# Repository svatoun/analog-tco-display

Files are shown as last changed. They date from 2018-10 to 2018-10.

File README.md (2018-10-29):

# analog-tco-display

Projekt se skládá z 2 částí: Analogové TCO a Zobrazovač obsazení

## Analogové TCO
**TCO je ovladač ANALOGOVÉHO kolejiště do ovládacího pultu**, pracuje s tlačítky (spínači) nebo přepínači. Čte stav tlačítek, sleduje změny a pomocí sběrnice RS485 odesílá jednotlivým výkonným zařízením pod kolejištěm. Sběrnice nahrazuje samostatné spínací / povelové vodiče vedoucí z pultu k jednotlivým servům, přestavníkům apod. TCO si vystačí se 3 vodiči (U+, U- a GND) a dokáže po nich přenést velké libovolné množství povelů.

Bežné "analogově řízené" kolejiště využívá jednoduchého spínání, tedy na každé zařízení (přestavník, lampa, světlo návěstidla atd) padne jeden vodič. Jejich množství může lehce vyčerpat vodiče v kabelu propojující ovládací panel s kolejištěm.

**POZOR** jedná se o ovládání ANALOGOVÉHO kolejiště, u digitálního kolejiště pomocí _XPressNet_ je pro komunikaci s centrálou použitá sicestejná kabeláž ale **jiný, standardizovaný, protokol** ! Komunikace a možnosti tohoto "analogového TCO" v žádném případě nedosahuje robustnosti a šíře protokolu XpressNet nebo LocoNet.

TCO se **konfiguruje** pomocí integrovaného USB portu v Arduinu, zapojeného do PC. 

Více viz [Analogové TCO](http://cs.ttodbocna.wikia.com/wiki/Analog_TCO)

## Zobrazení obsazení
Skládá se z několika částí:
- Proudové detektory obsazení uzpůsobené pro analogový provoz
- Enkodér detektorů pro sběrnici S88 (stejná jako se používá u digitalních kolejišť)
- Zobrazovací jednotka v ovládacím pultu
Umožňuje přenášet až 128 detekovaných úseků a zobrazovat jejich stav na ovládacím pultu. Umožňuje také do přenášených dat zapojit jiný tzp detektorů, 
např. jazýčková relé, optické senzory atd. 

Podrobnější popis bude doplněn.

## Celková "architektura"
Jak spolu spolupracují TCO, Display, proudove detektory atd atd je [vysvětleno ve Wiki](http://cs.ttodbocna.wikia.com/wiki/Architektura_Analog)

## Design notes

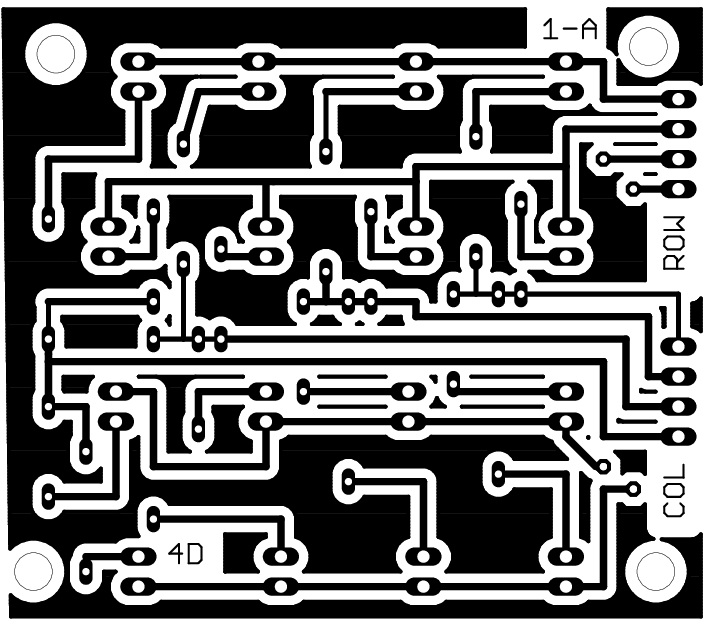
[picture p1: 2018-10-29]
eagle/tco/matrix4x4-b.png

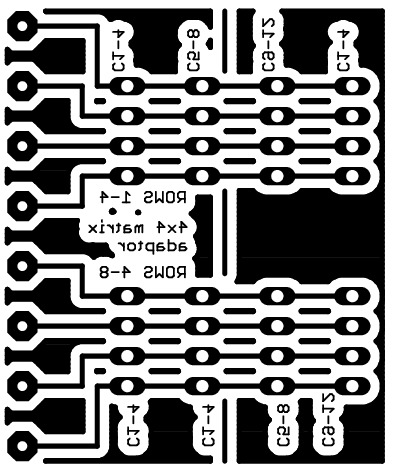
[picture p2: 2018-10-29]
eagle/tco/matrixkey-adapter.png

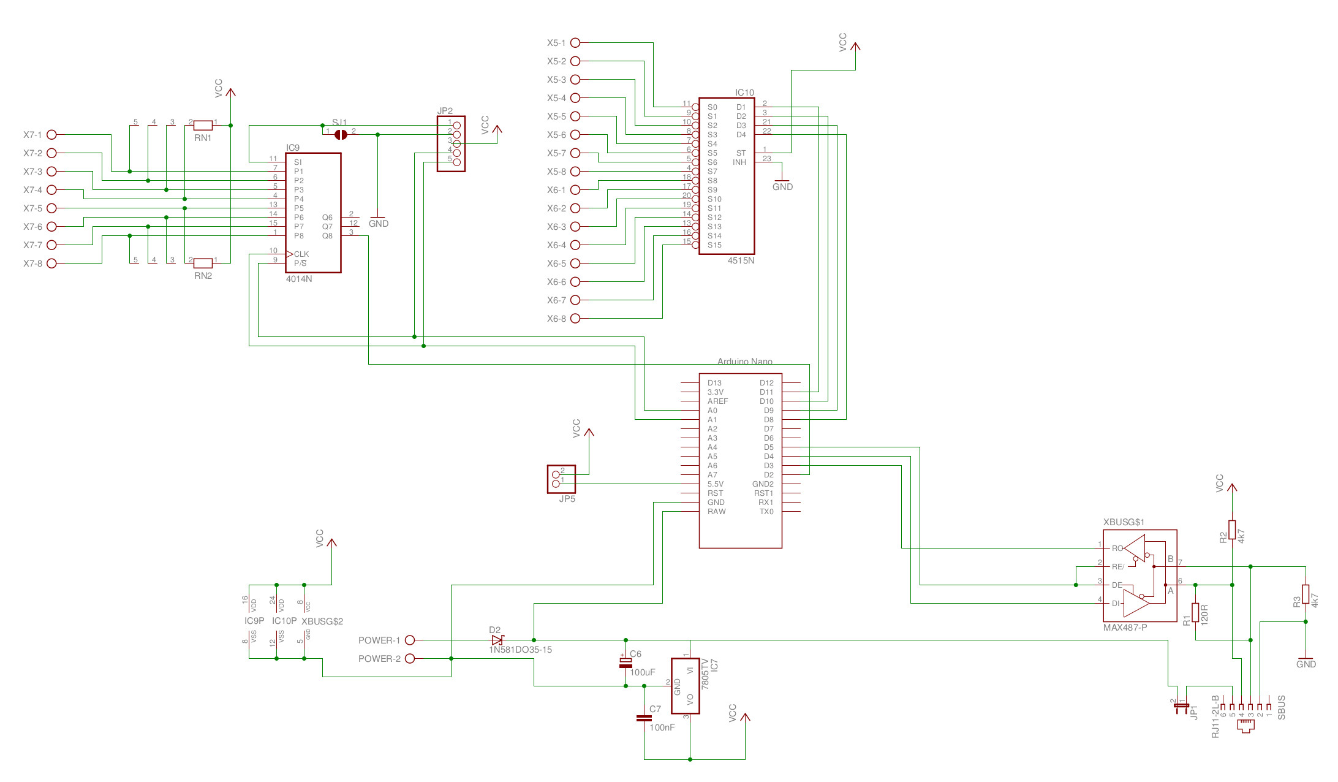
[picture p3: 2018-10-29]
eagle/tco/analogTCO-RJ-alone-ext-schema.jpg

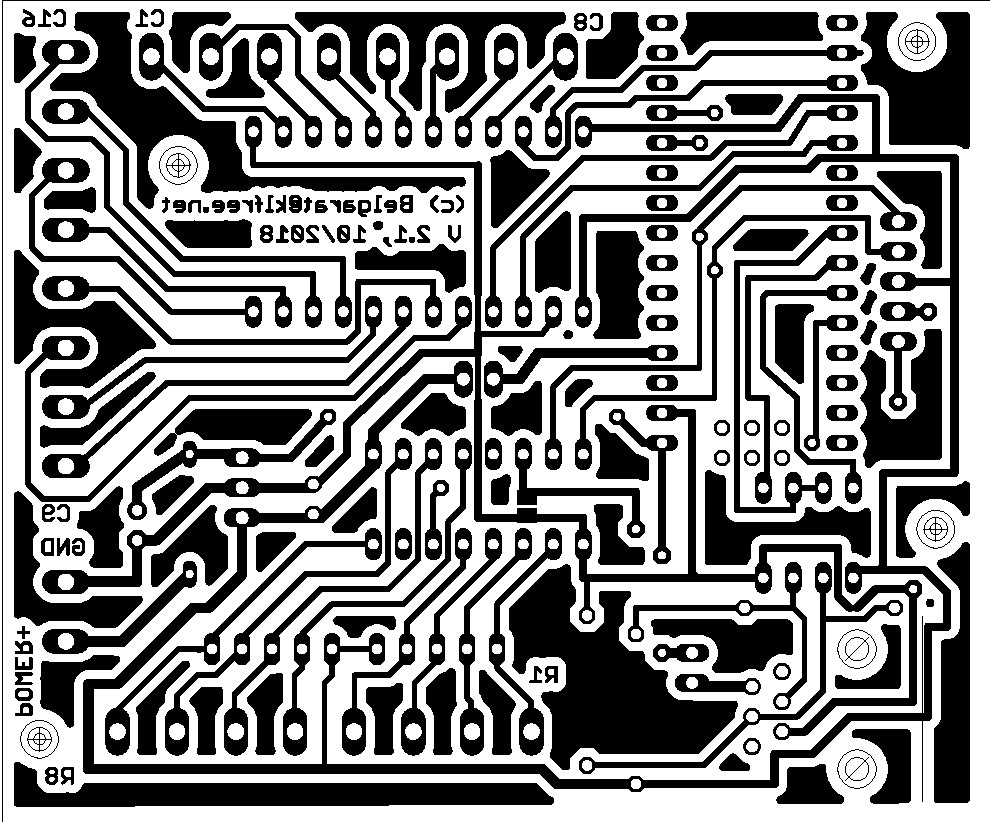
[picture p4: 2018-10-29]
eagle/tco/analogTCO-RJ-alone-ext.jpg

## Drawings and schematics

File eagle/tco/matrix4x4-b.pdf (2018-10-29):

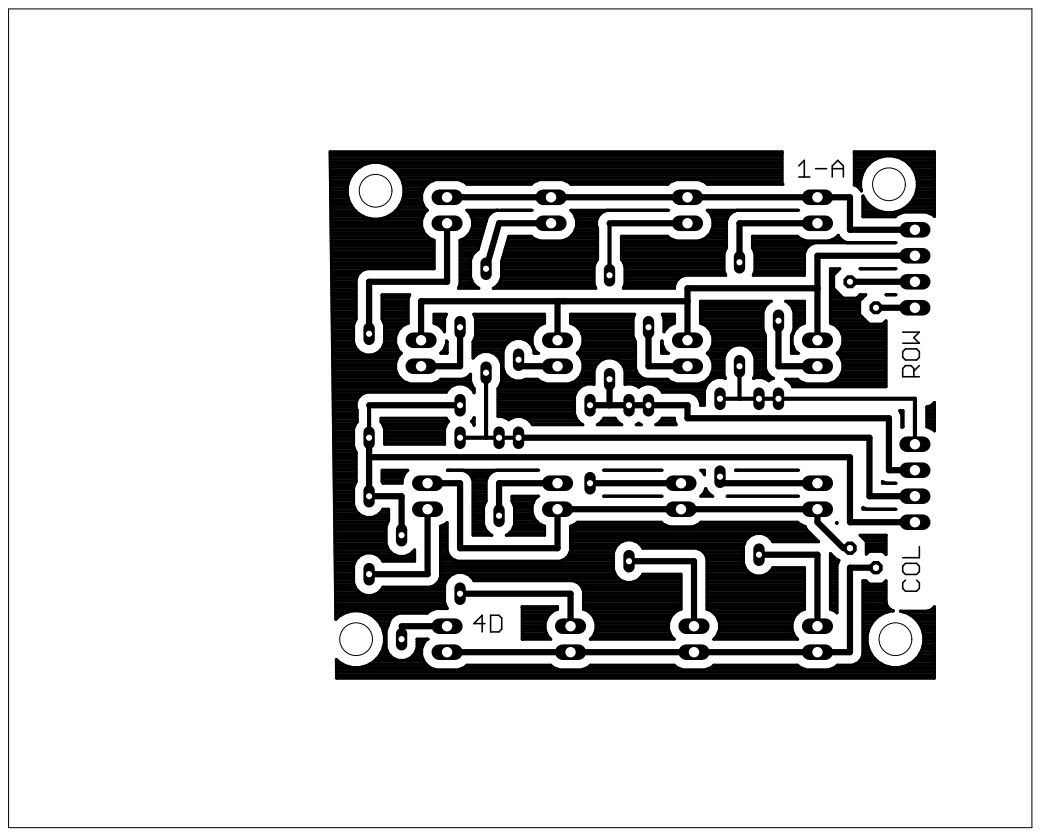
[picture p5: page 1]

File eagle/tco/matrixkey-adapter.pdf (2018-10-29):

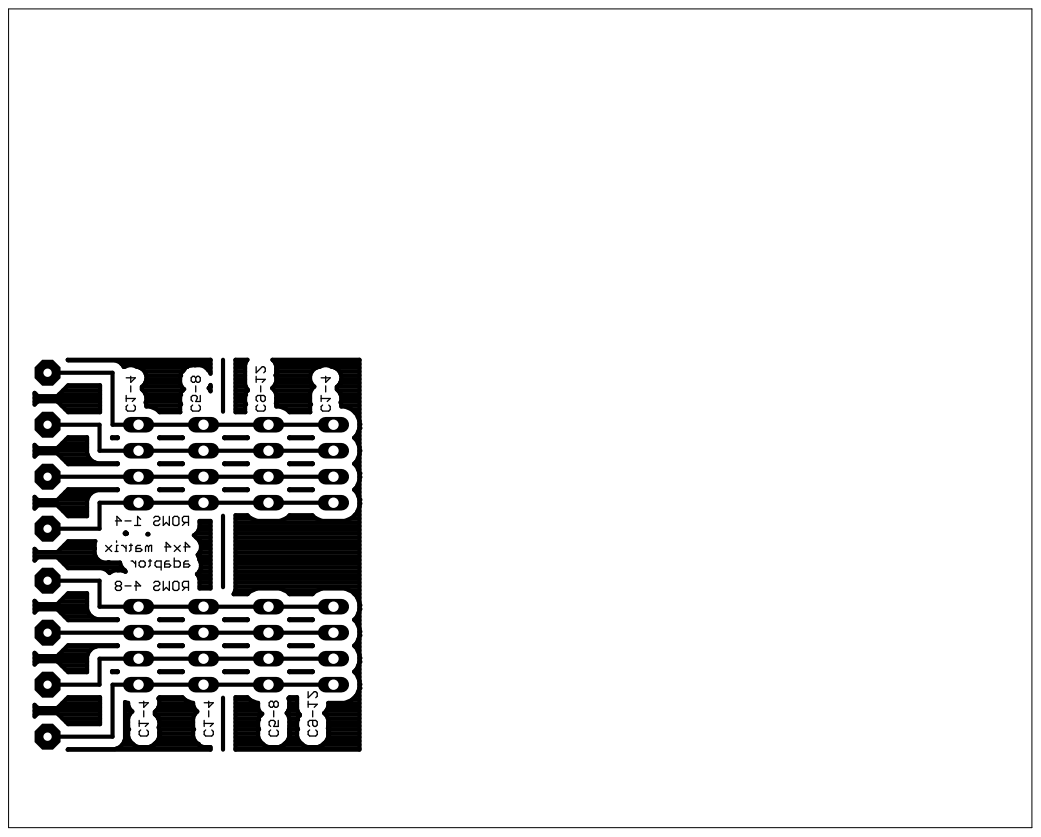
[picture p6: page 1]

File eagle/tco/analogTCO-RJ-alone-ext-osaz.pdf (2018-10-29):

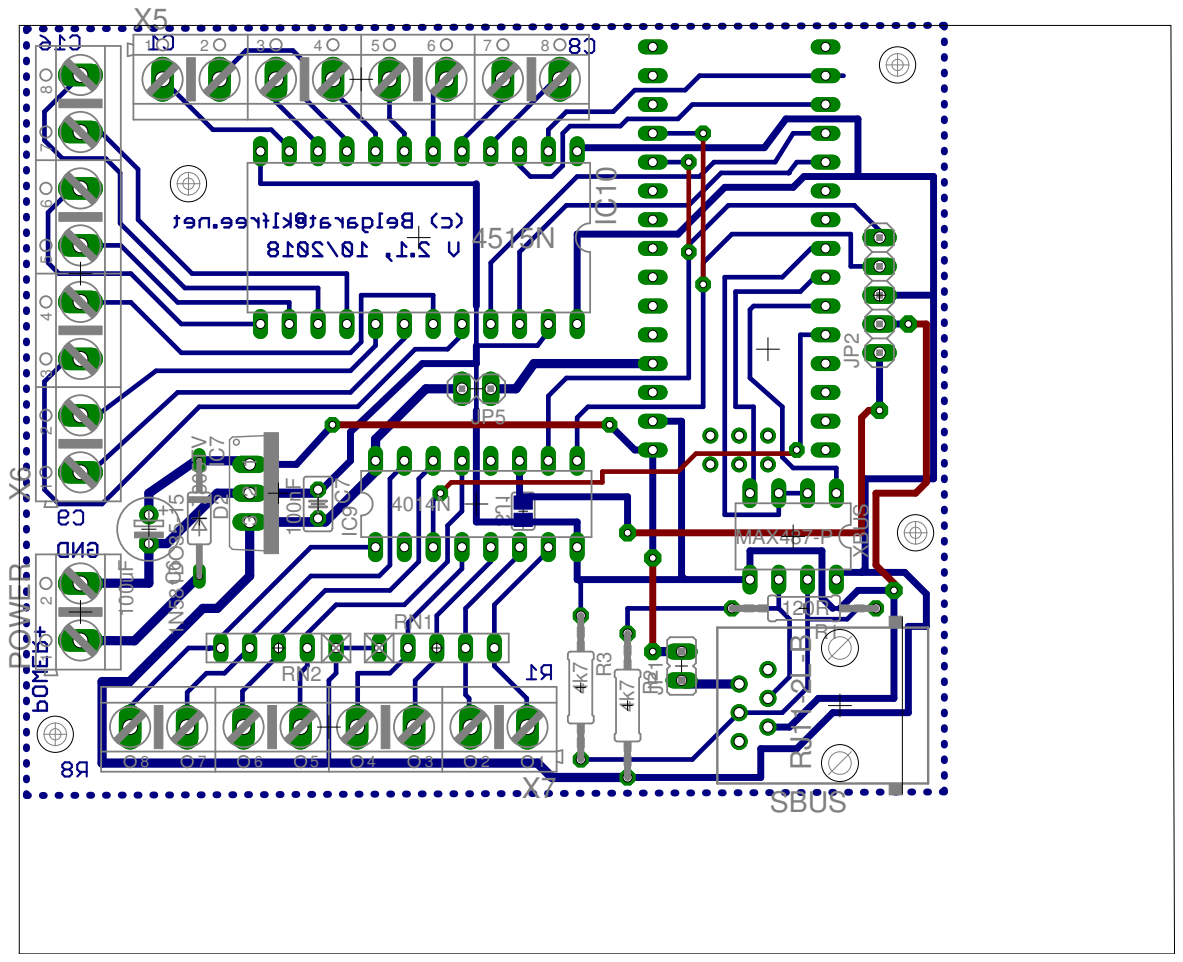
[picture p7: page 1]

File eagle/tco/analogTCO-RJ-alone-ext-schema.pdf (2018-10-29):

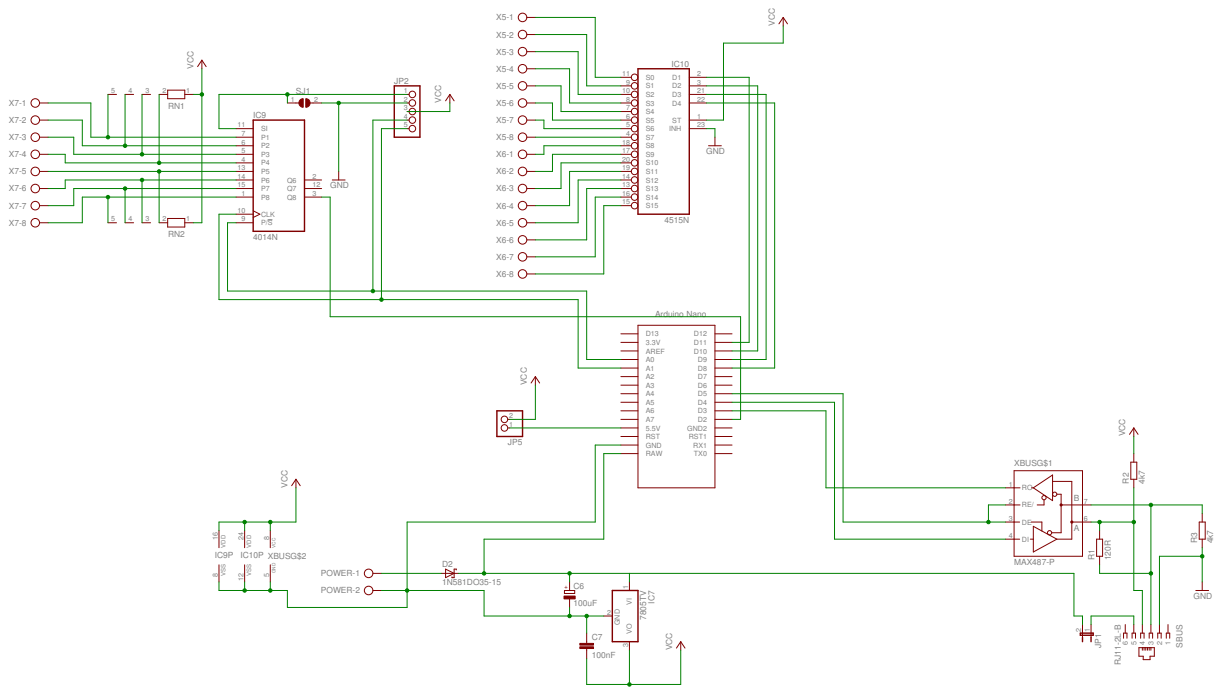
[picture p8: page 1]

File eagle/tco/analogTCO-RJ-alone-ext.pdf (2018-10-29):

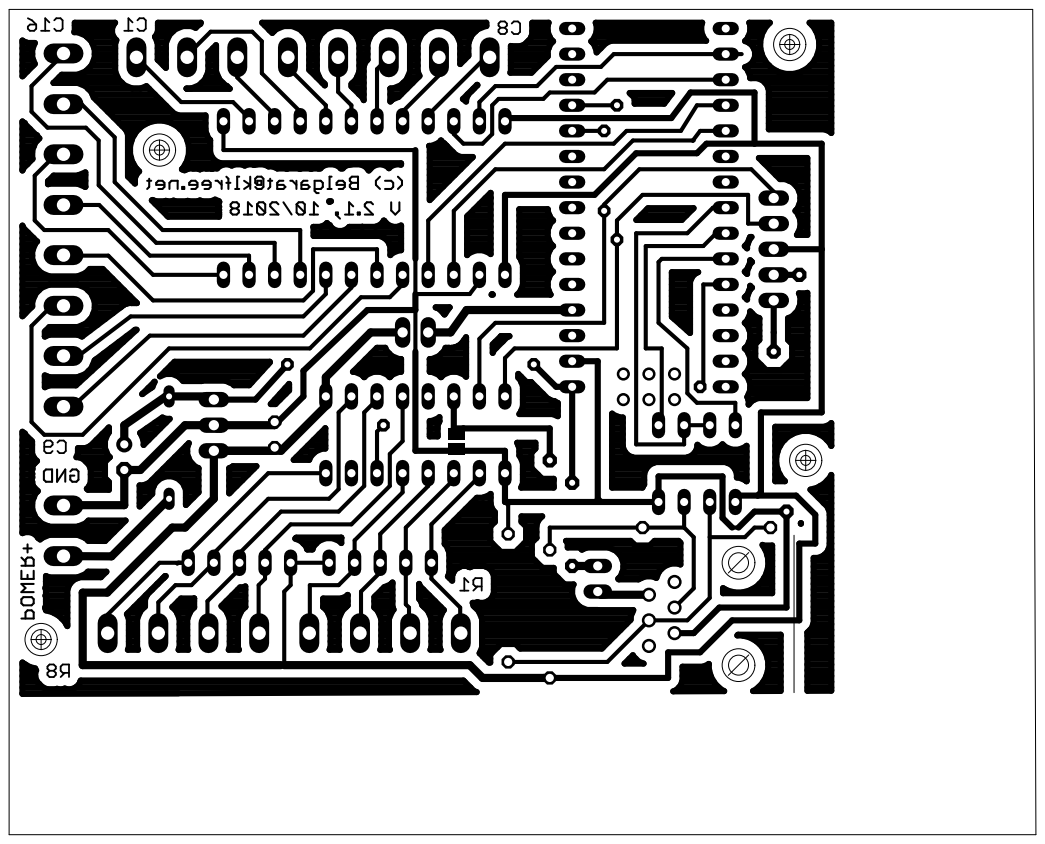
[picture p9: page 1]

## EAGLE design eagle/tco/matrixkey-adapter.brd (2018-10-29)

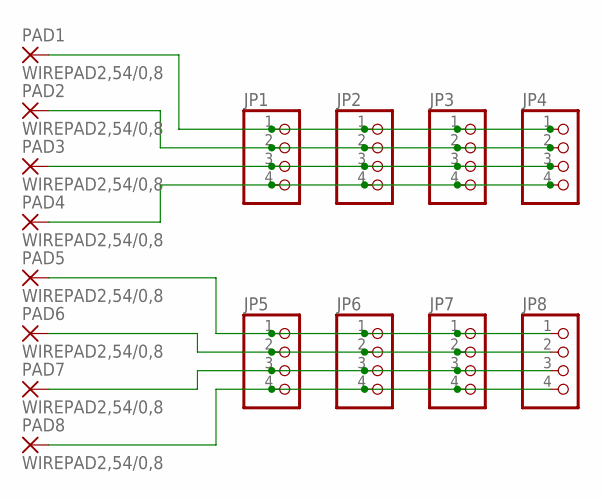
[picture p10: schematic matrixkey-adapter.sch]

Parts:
JP1, JP2, JP3, JP4, JP5, JP6, JP7, JP8: PINHD-1X4; 1X04
PAD1, PAD2, PAD3, PAD4, PAD5, PAD6, PAD7, PAD8: WIREPAD2,54/0,8; 2,54/0,8

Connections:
unnamed: JP1.1, JP2.1, JP3.1, JP4.1, PAD1.1
unnamed: JP1.2, JP2.2, JP3.2, JP4.2, PAD2.1
unnamed: JP1.3, JP2.3, JP3.3, JP4.3, PAD3.1
unnamed: JP1.4, JP2.4, JP3.4, JP4.4, PAD4.1
unnamed: JP5.1, JP6.1, JP7.1, JP8.1, PAD5.1
unnamed: JP5.2, JP6.2, JP7.2, JP8.2, PAD6.1
unnamed: JP5.3, JP6.3, JP7.3, JP8.3, PAD7.1
unnamed: JP5.4, JP6.4, JP7.4, JP8.4, PAD8.1

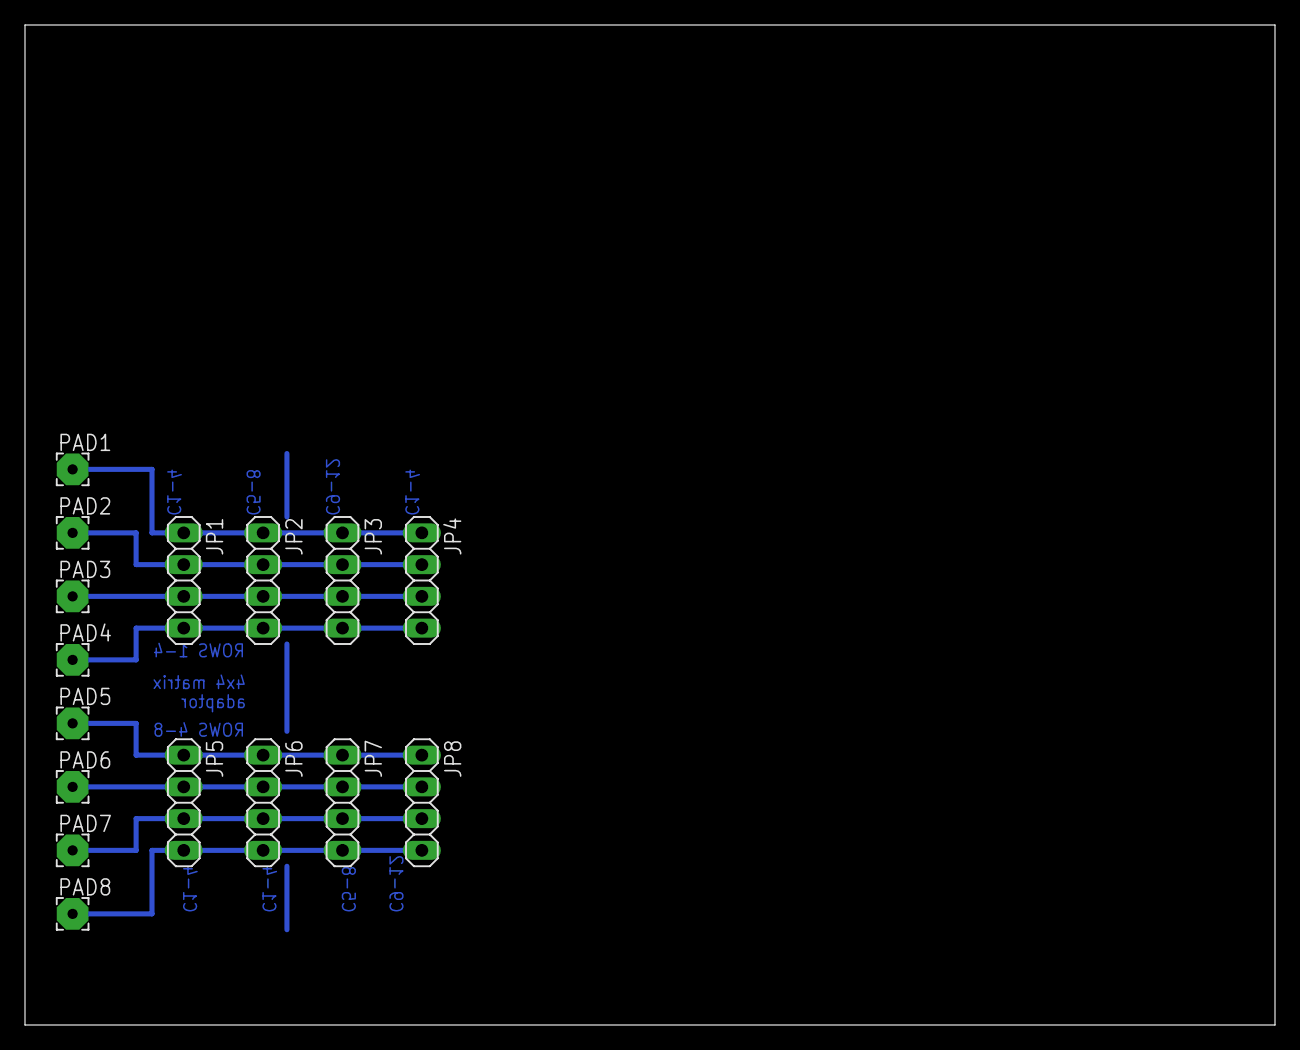
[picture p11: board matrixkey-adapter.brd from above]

Board: 2 copper layers, 100.0 x 80.0 mm, 16 parts (0 on the bottom side), 8 nets.

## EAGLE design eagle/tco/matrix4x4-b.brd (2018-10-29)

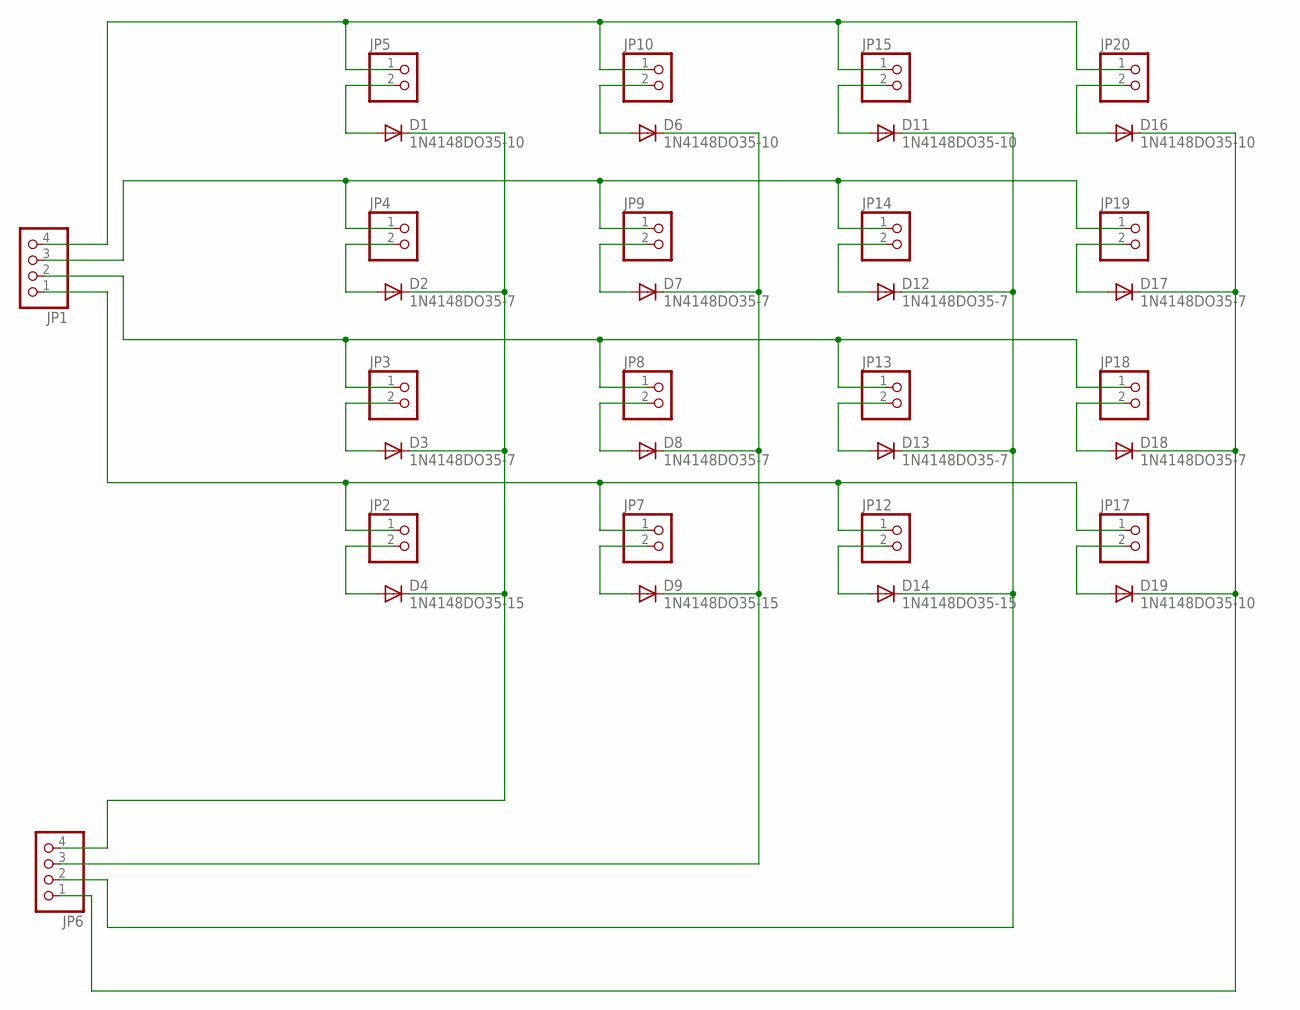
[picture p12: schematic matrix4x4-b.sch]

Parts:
D1, D6, D11, D16, D19: 1N4148DO35-10; DO35-10
D2, D3, D7, D8, D12, D13, D17, D18: 1N4148DO35-7; DO35-7
D4, D9, D14: 1N4148DO35-15; DO35-10
JP1, JP6: PINHD-1X4; 1X04
JP2, JP3, JP4, JP5, JP7, JP8, JP9, JP10, JP12, JP13, JP14, JP15, JP17, JP18, JP19, JP20: PINHD-1X2; 1X02

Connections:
unnamed: JP1.1, JP2.1, JP7.1, JP12.1, JP17.1
unnamed: JP1.2, JP3.1, JP8.1, JP13.1, JP18.1
unnamed: JP1.3, JP4.1, JP9.1, JP14.1, JP19.1
unnamed: JP1.4, JP5.1, JP10.1, JP15.1, JP20.1
unnamed: D1.A, JP5.2
unnamed: D2.A, JP4.2
unnamed: D4.A, JP2.2
unnamed: D1.C, D2.C, D3.C, D4.C, JP6.4
unnamed: D6.C, D7.C, D8.C, D9.C, JP6.3
unnamed: D11.C, D12.C, D13.C, D14.C, JP6.2
unnamed: D16.C, D17.C, D18.C, D19.C, JP6.1
unnamed: D6.A, JP10.2
unnamed: D7.A, JP9.2
unnamed: D9.A, JP7.2
unnamed: D3.A, JP3.2
unnamed: D8.A, JP8.2
unnamed: D13.A, JP13.2
unnamed: D18.A, JP18.2
unnamed: D11.A, JP15.2
unnamed: D12.A, JP14.2
unnamed: D14.A, JP12.2
unnamed: D16.A, JP20.2
unnamed: D17.A, JP19.2
unnamed: D19.A, JP17.2

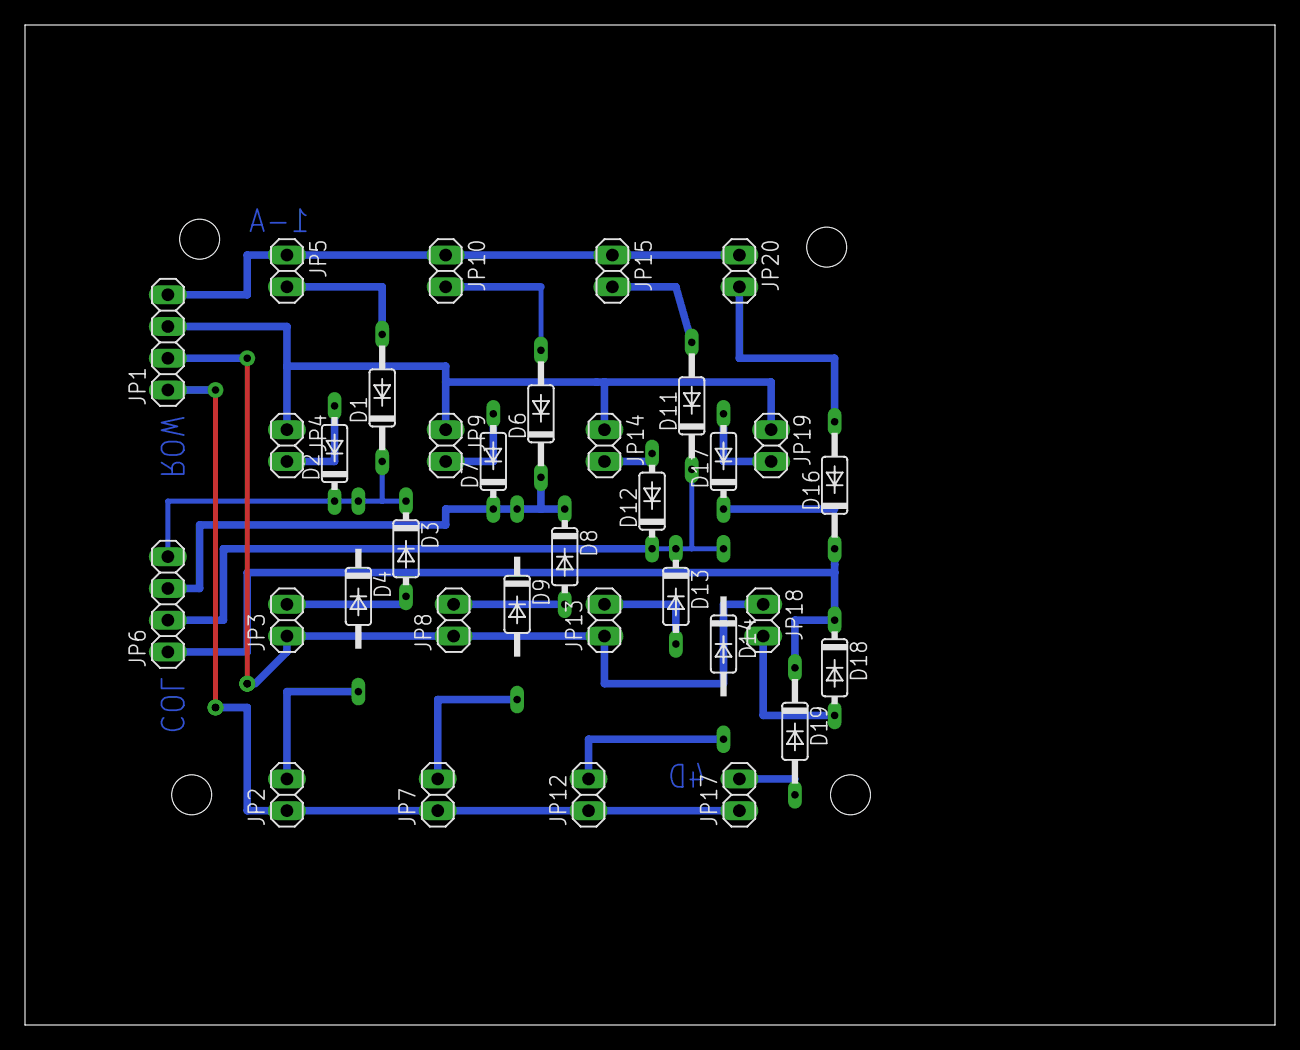
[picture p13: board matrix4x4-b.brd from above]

Board: 2 copper layers, 100.0 x 80.0 mm, 34 parts (0 on the bottom side), 24 nets.

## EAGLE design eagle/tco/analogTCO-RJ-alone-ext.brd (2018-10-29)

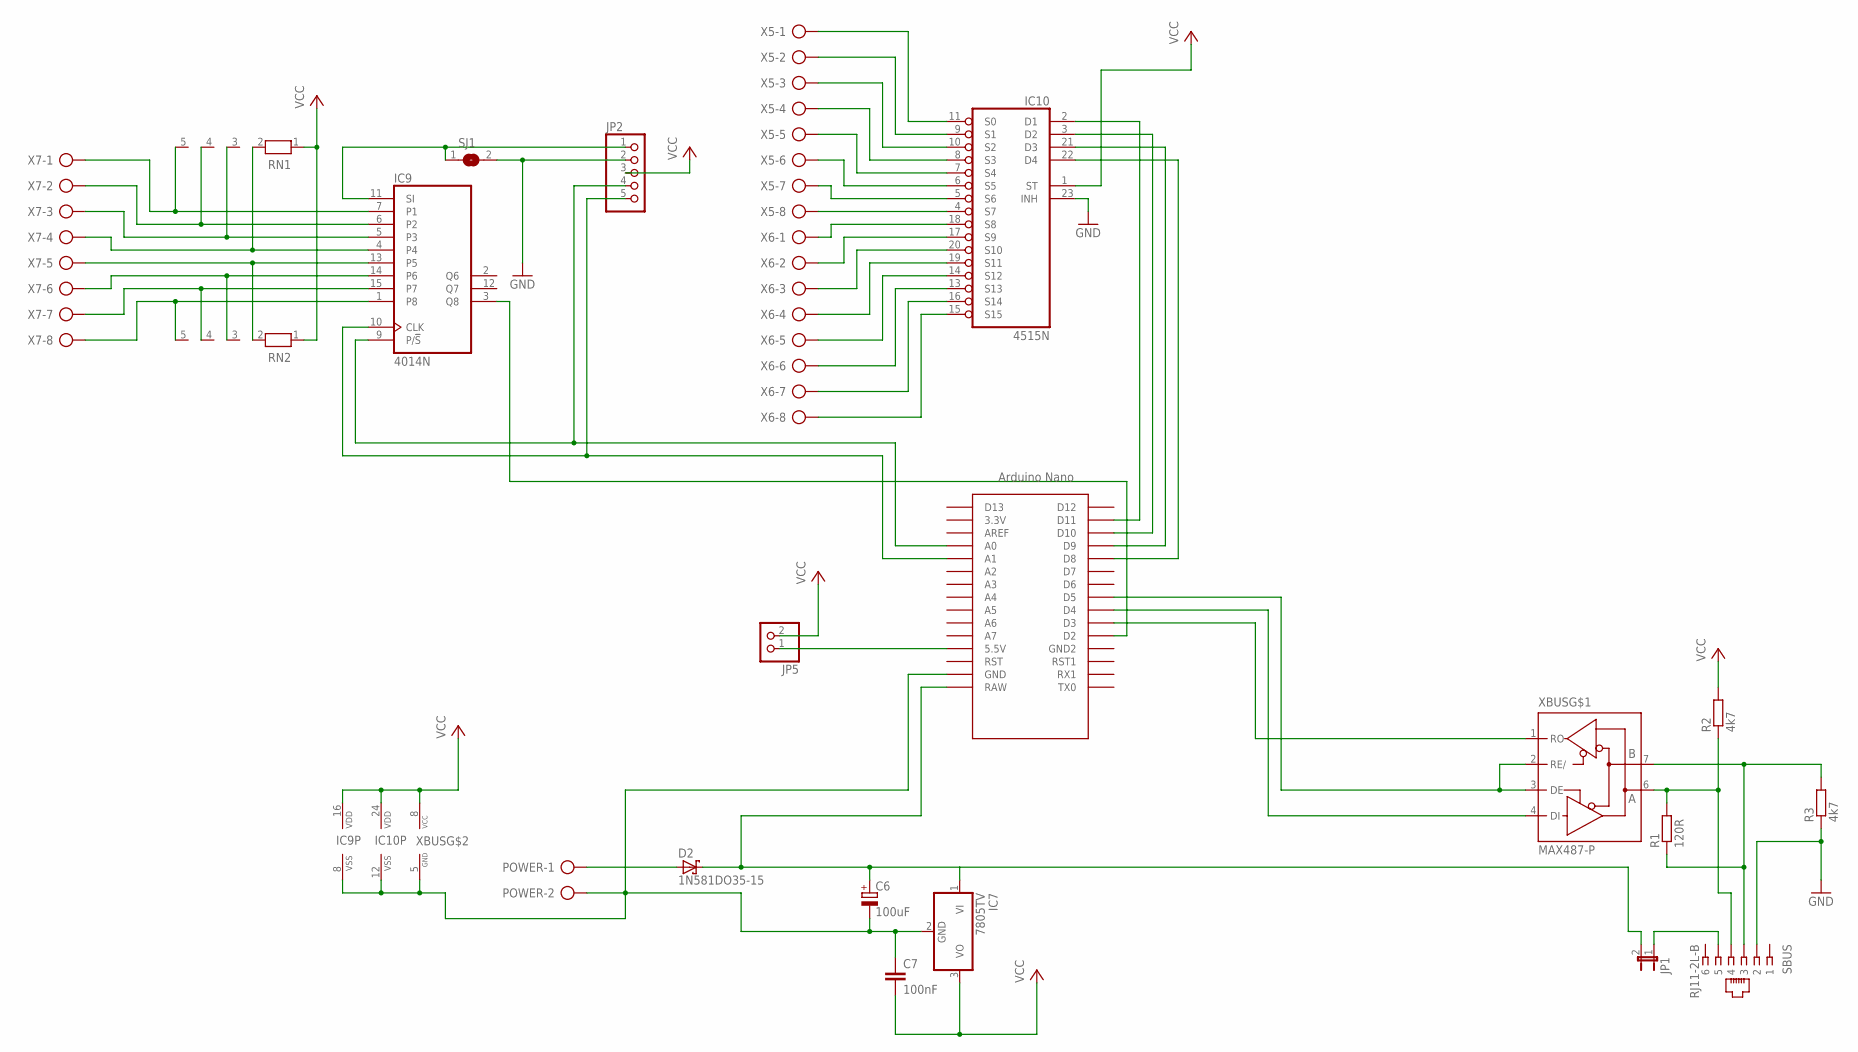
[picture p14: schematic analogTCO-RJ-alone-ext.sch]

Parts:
C6: 100uF; E2,5-6
C7: 100nF; C025-025X050
D2: 1N581DO35-15; DO35-10
IC7: 7805TV; TO220V
IC9: 4014N; DIL16
IC10: 4515N; DIL24-6
JP1: JP1E; JP1
JP2: PINHD-1X5; 1X05
JP5: PINHD-1X2; 1X02
POWER: AK500/2
R1: 120R; 0207/12
R2, R3: 4k7; 0207/12
RN1, RN2: RN04; RN-5
SBUS: RJ11-2L-B; RJ11-NO_SHIELD
SJ1: SJ
U$1: NANO
X5, X6, X7: AK500/8
XBUS: MAX487-P; DIL08

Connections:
+12V: C6.+, D2.C, IC7.1 (VI), JP1.2, U$1.RAW
GND: C6.-, C7.1, IC7.2 (GND), IC9.8 (VSS), IC10.12 (VSS), IC10.23 (INH), JP2.2, POWER.2, R3.1, SBUS.2, SJ1.2, U$1.GND, XBUS.5 (GND)
unnamed: U$1.D5, XBUS.2 (RE/), XBUS.3 (DE)
unnamed: U$1.D3, XBUS.1 (RO)
unnamed: U$1.D4, XBUS.4 (DI)
unnamed: R1.2, R2.1, SBUS.4, XBUS.6 (A)
unnamed: R1.1, R3.2, SBUS.3, XBUS.7 (B)
unnamed: JP5.1, U$1.5V (5.5V)
unnamed: JP1.1, SBUS.5
unnamed: IC9.11 (SI), JP2.1, SJ1.1
unnamed: IC10.3 (D2), U$1.D10
unnamed: IC10.2 (D1), U$1.D11
unnamed: IC9.9 (P/!S), JP2.4, U$1.A0
unnamed: IC9.10 (CLK), JP2.5, U$1.A1
unnamed: IC9.3 (Q8), U$1.D2
unnamed: IC10.11 (S0), X5.1
unnamed: IC10.9 (S1), X5.2
unnamed: IC10.10 (S2), X5.3
unnamed: IC10.8 (S3), X5.4
unnamed: IC10.7 (S4), X5.5
unnamed: IC10.6 (S5), X5.6
unnamed: IC10.5 (S6), X5.7
unnamed: IC10.4 (S7), X5.8
unnamed: IC10.18 (S8), X6.1
unnamed: IC10.17 (S9), X6.2
unnamed: IC10.20 (S10), X6.3
unnamed: IC10.19 (S11), X6.4
unnamed: IC10.14 (S12), X6.5
unnamed: IC10.13 (S13), X6.6
unnamed: IC10.16 (S14), X6.7
unnamed: IC10.15 (S15), X6.8
unnamed: IC9.7 (P1), RN1.5, X7.1
unnamed: IC9.6 (P2), RN1.4, X7.2
unnamed: IC9.5 (P3), RN1.3, X7.3
unnamed: IC9.4, RN1.2, X7.4
unnamed: IC9.13 (P5), RN2.2, X7.5
unnamed: IC9.14 (P6), RN2.3, X7.6
unnamed: IC9.15 (P7), RN2.4, X7.7
unnamed: IC9.1 (P8), RN2.5, X7.8
unnamed: IC10.21 (D3), U$1.D9
unnamed: IC10.22 (D4), U$1.D8
unnamed: D2.A, POWER.1
VCC: C7.2, IC7.3 (VO), IC9.16 (VDD), IC10.1 (ST), IC10.24 (VDD), JP2.3, JP5.2, R2.2, RN1.1, RN2.1, XBUS.8 (VCC)

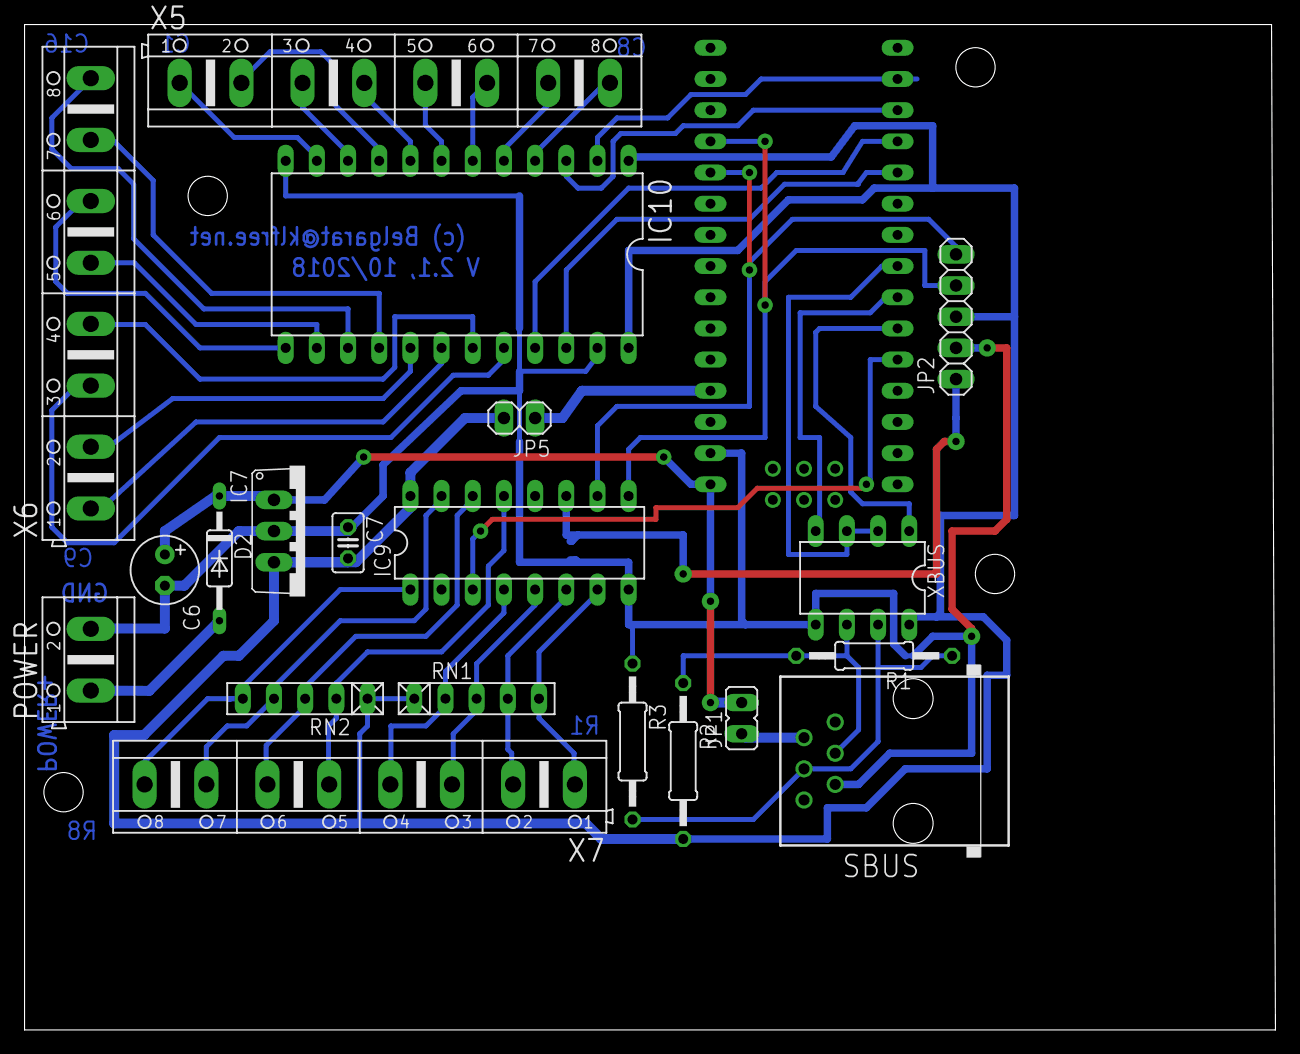
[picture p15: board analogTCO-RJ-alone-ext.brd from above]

Board: 2 copper layers, 101.9 x 81.9 mm, 22 parts (1 on the bottom side), 43 nets.

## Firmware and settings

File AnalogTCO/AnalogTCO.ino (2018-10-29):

#undef NEO
#ifdef NEO
#include <NeoSWSerial.h>
#else
#include <SoftwareSerial.h>
#endif

#include <EEPROM.h>

#include "Config.h"
#include "Utils.h"
#include "Debounce.h"
#include "RS485Frame.h"
#include "EEData.h"
#include "Common.h"

const boolean debugControl = false;

EEData eeData;

char printBuffer[50];

/**
 * Aktualni cas, milisekundy. Nastaveno v kazdem loop-u. Rychlejsi
 * nez neustale cteni millis()
 */
unsigned long currentMillis = 0;
/**
 * Spodnich 16 bitu casu. Vyuziva se pro rychle timery (0-64k = cca 60 sec.)
 */
unsigned int currentMillisLow = 0;

unsigned long start = micros();

/**
 * Cislo radku pro adresu demultiplexeru 4514 a 4515
 */
byte ioRowIndex = 0;

/**
 * Nastavi provoz pro porty demultiplexeru
 */
void setupDemuxPorts() {
  pinMode(DemuxAddr0, OUTPUT);
  pinMode(DemuxAddr1, OUTPUT);
  pinMode(DemuxAddr2, OUTPUT);
  pinMode(DemuxAddr3, OUTPUT);
  // a zaroven nastavi pocatecni adresu
  selectDemuxLine(ioRowIndex);
}

/**
 * Nastavi postupne porty pro vsechny podsystemy
 */
void setupPorts() {
  setupRS485Ports();
  setupInputPorts();

  setupDemuxPorts();
}


/**
 * Prejde na dalsi radek klavesnice, a zobrazovaci
 * matice
 */
void advanceRowIndex() {
  selectDemuxLine(ioRowIndex);
}

/**
   Writes a block of data into the EEPROM, followed by a checksum
*/
void eeBlockWrite(byte magic, int eeaddr, const void* address, int size) {
  if (debugControl) {
    Serial.print(F("Writing EEPROM ")); Serial.print(eeaddr, HEX); Serial.print(F(":")); Serial.print(size); Serial.print(F(", source: ")); Serial.println((int)address, HEX);
  }
  const byte *ptr = (const byte*) address;
  byte hash = magic;
  EEPROM.write(eeaddr, magic);
  eeaddr++;
  for (; size > 0; size--) {
    byte b = *ptr;
    EEPROM.write(eeaddr, b);
    ptr++;
    eeaddr++;
    hash = hash ^ b;
  }
  EEPROM.write(eeaddr, hash);
}

/**
   Reads block of data from the EEPROM, but only if the checksum of
   that data is correct.
*/
boolean eeBlockRead(byte magic, int eeaddr, void* address, int size) {
  if (debugControl) {
    Serial.print(F("Reading EEPROM ")); Serial.print(eeaddr, HEX); Serial.print(F(":")); Serial.print(size); Serial.print(F(", dest: ")); Serial.println((int)address, HEX);
  }
  int a = eeaddr;
  byte hash = magic;
  byte x;
  boolean allNull = true;
  x = EEPROM.read(a);
  if (x != magic) {
    if (debugControl) {
      Serial.println(F("No magic header found"));
    }
    return false;
  }
  a++;
  for (int i = 0; i < size; i++, a++) {
    x = EEPROM.read(a);
    if (x != 0) {
      allNull = false;
    }
    hash = hash ^ x;
  }
  x = EEPROM.read(a);
  if (hash != x || allNull) {
    if (debugControl) {
      Serial.println(F("Checksum does not match"));
    }
    return false;
  }

  a = eeaddr + 1;
  byte *ptr = (byte*) address;
  for (int i = 0; i < size; i++, a++) {
    x = EEPROM.read(a);
    *ptr = x;
    ptr++;
  }
}

void checkInitEEPROM() {
  int savedVer = EEPROM.read(eeaddr_version);
  if (savedVer == CURRENT_DATA_VERSION) {
    return;
  }
  Serial.println(F("Obsolete EEPROM, reinitializing"));
  EEPROM.write(eeaddr_version, CURRENT_DATA_VERSION);
  resetAll();
  saveAll();
}


void setup() {
  Serial.begin(115200);
  setupPorts();
  
  resetBusMaster();
  resetInput();
  checkInitEEPROM();
  loadAll();
  initTerminal();

  registerLineCommand("EED", &commandDumpEEProm);
  registerLineCommand("DMP", &commandDumpAll);
  registerLineCommand("CLR", &commandClear);
  registerLineCommand("SAV", &commandSave);
  registerLineCommand("XDR", &commandSbusAddress);

//  testCommunication();

  Serial.print(F("Analog Control Panel, version ")); Serial.print(majorVersion); Serial.print('.'); Serial.println(minorVersion);
  Serial.println(F("Copyright (c) 2018, belgarat@klfree.net; licensed under Apache License 2.0 "));
  Serial.println();
  printPrompt();
}

void resetAll() {
  eeData = EEData();
  resetInput();
}

void saveAll() {
  eeBlockWrite('C', eeaddr_config, &eeData, sizeof(eeData));
}


void loadAll() {
  eeBlockRead('C', eeaddr_config, &eeData, sizeof(eeData));
}

/**
 * Casovac pro zpracovani radek klavesnice.
 */
unsigned int lastIORowStart = 0;

/**
 * Zpracuje jeden radek klavesnice a vystupu, ale nejdrive za
 * `ioRowSwitchDelay` milisekund; to zajisti urcitou dobu sviceni
 * LEDek v radku
 */
void shiftIORow() {
  if (!elapsedTime(lastIORowStart, ioRowSwitchDelay)) {
    return;
  }
  
  selectDemuxLine(ioRowIndex);
  
  processInputRow();
  ioRowIndex = (ioRowIndex + 1) % inputRows;
//  ioRowIndex = 0;
}

const boolean testOnly = true;

extern volatile long  intCount;
void loop() {
  updateTime();
    
  shiftIORow();
  updateTime();
  transmitFrames();

  updateTime();
//  processS88Bus();

  updateTime();
//  flipFlashes();
  processTerminal();
}

void commandClear() {
  Serial.println(F("Clearing all settings"));
  resetAll();
  saveAll();
  commandReset();
}

void commandDumpEEProm() {
  Serial.println(F("EEPROM Dump:"));
  char buffer[24 + 4 + 2];
  int cnt = 0;
  char *ptr = buffer;
  *ptr = 0;
  for (int eea = 0; eea < eeaddr_top; eea++) {
    int r = EEPROM.read(eea);
    if (r < 0x10) {
      *(ptr++) = '0';
    }
    ptr = printNumber(ptr, r, 16);
    append(ptr, ' ');
    cnt++;
    if (cnt %32 == 0) {
      Serial.println(buffer);
      *(ptr = buffer) = 0;
    } else if (cnt % 8 == 0) {
      Serial.print(buffer);
      Serial.print(F("- "));
      *(ptr = buffer) = 0;
    }
  }
  Serial.println(buffer);
}

void commandSave() {
  saveAll();
  Serial.println(F("All saved to EEPROM"));
}

void commandDumpAll() {
  commandShowKeys();
}

void printFeatures() {
  if (eeData.enableTrack && eeData.enableKeys && eeData.enableS88) {
    Serial.println(F("FTR:a:1"));
    return;
  }
  Serial.print(F("FTR:t:")); Serial.println(eeData.enableTrack);
  Serial.print(F("FTR:k:")); Serial.println(eeData.enableKeys);
  Serial.print(F("FTR:s:")); Serial.println(eeData.enableS88);
}

void commandFeature() {
  char f = *inputPos;
  if (f == 0) {
    printFeatures();
    return;
  }
  ++inputPos;
  if (*inputPos != ':') {
    Serial.println(F("Bad syntax"));
    return;
  }
  inputPos++;
  boolean en;
  switch (*inputPos) {
    case '1': case '+': case 'y':
      en = 1; break;
    case '0': case '-': case 'n':
      en = 0; break;
    default:
      Serial.println(F("Bad state"));
      return;
  }
  switch (f) {
    case 'a':
      eeData.enableTrack = eeData.enableKeys = eeData.enableS88 = en;
      break;
    case 't': eeData.enableTrack = en; break; 
    case 'k': eeData.enableKeys = en; break; 
    case 's': eeData.enableS88 = en; break; 
    default:
      Serial.println(F("Bad feature"));
      return;
  }
}

void dumpSbusAddress() {
  Serial.print(F("XDR:")); Serial.println(eeData.busId);
}
void commandSbusAddress() {
  int a = nextNumber();
  if (a == -2) {
    dumpSbusAddress();
    return;
  }
  if (a < 1) {
    Serial.println(F("Bad addr"));
    return;
  }
  eeData.busId = a;
}

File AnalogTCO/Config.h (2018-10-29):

/**
 * Delay after one I/O row was processed, outputs are lit and before
 * the processing changes io demux to the next row.
 */
const int ioRowSwitchDelay = 0;
//const int ioRowSwitchDelay = 1000;
const int keyboardDebounceTime = 50;
const int maxContinuousTransfer = 30;

const byte s88ModuleCount = 4;

/**
 * Velikost prijmoveho bufferu v byte. Musi byt delsi nez nejdelsi zpracovavany packet.
 * Delsi packety se ani nezaznamenavaji a zahazuji rovnou.
 */
const int recvBufferSize = 20;


////////////////////// S88 input pin assignments ///////////////////////
/**
 * Vstup z S88 sbernice
 */
const int S88Input = A6;

/**
 * Hodiny pro S88 
 */
const int S88Clock = A5;

/**
 * LOAD signal. Kdyz se zmeni na HIGH, S88 moduly nactou data ze stradacu
 */
const int S88Latch = A4;

/**
 * RESET signal, na std. vodici #6
 */
const int S88ResetAll = A3;

/**
 * RESET signal, ale jen je-li v kolejich napeti
 */
const int S88ResetTrack = A2;

/**
 * Vstup pro mereni napeti v kolejich
 */
const int S88TrackInput = A7;


////////////////////// Feedback POWER+ SHIFT REGISTER ///////////////////////
const int SHIFTREG_CLOCK_COMMON = A1;

/**
 * Clock for shift register which controls power+ for feedback LEDs
 */
const int FbPowerClock = SHIFTREG_CLOCK_COMMON;
/**
 * Data sent to the feedback power+ shift register
 */
const int FbPowerData = 7;
/**
 * Enables output on the data
 */
const int FbPowerLatch = 6;

////////////////////// TCO pullup latches SHIFT REGISTER ///////////////////////
const int TcInputClock = SHIFTREG_CLOCK_COMMON;
const int TcInputData = 2;

//const int TcInputClock = 13;
//const int TcInputData = 12;

const int TcInputLatch = A0;

////////////////////// RS485 communication pins //////////////////////
const int rs485Receive = 3;
const int rs485Send = 4;
const int rs485Direction = 5;

////////////////////// Feedback POWER- DEMUX, keyboard GND demux  ///////////////////////
const int DemuxAddr3 = 8;
const int DemuxAddr2 = 9;
const int DemuxAddr1 = 10;
const int DemuxAddr0 = 11;


const byte inputRows = 16;
const byte inputColumns = 8;

static_assert(inputRows == 8 || inputRows == 16, "Either 8 or 16 rows must be selected");

const byte outputRows = 16;
const byte outputColumns = 8;

const byte maxRowCount = max(inputRows, outputRows);
const byte maxColumnCount = max(inputColumns, outputColumns);


const byte maxKeyTranslations = 32;
const byte outputByteSize = (outputRows * outputColumns + 7) / 8;

const byte maxTarget = 16;

const int majorVersion = 0;
const int minorVersion = 1;

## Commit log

2018-10-29 Male opravy z psani dokumentace
    [analogTCO-RJ-alone-ext.brd, analogTCO-RJ-alone.sch]
2018-10-29 Spravna verze schematu
    [analogTCO-RJ-alone-ext.sch]
2018-10-29 Pridana matice pro tlacitka s diodami; adapter pro matice do svorkovnice
    [matrix4x4-b.brd, matrix4x4-b.sch, matrixkey-adapter.brd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]
